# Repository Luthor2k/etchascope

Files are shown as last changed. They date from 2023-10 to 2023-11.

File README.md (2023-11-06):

# EtchaSkope
Supercon 2023 Badge Expansion
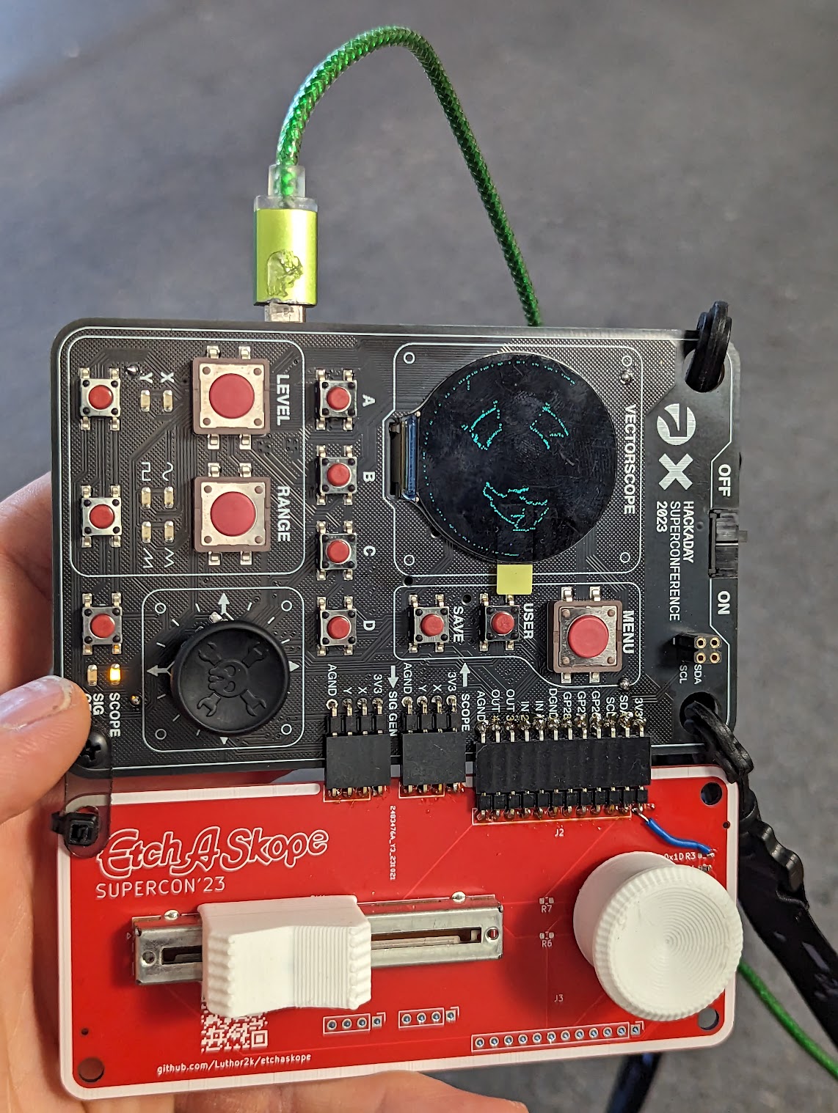
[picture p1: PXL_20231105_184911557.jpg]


## Two bodge wires needed!
The high speed DAQ on the badge was the wrong choice, reroute the linear pot to the RP2040 ADC. Also need to bring 3.3V to a pull up because of a routing mistake.
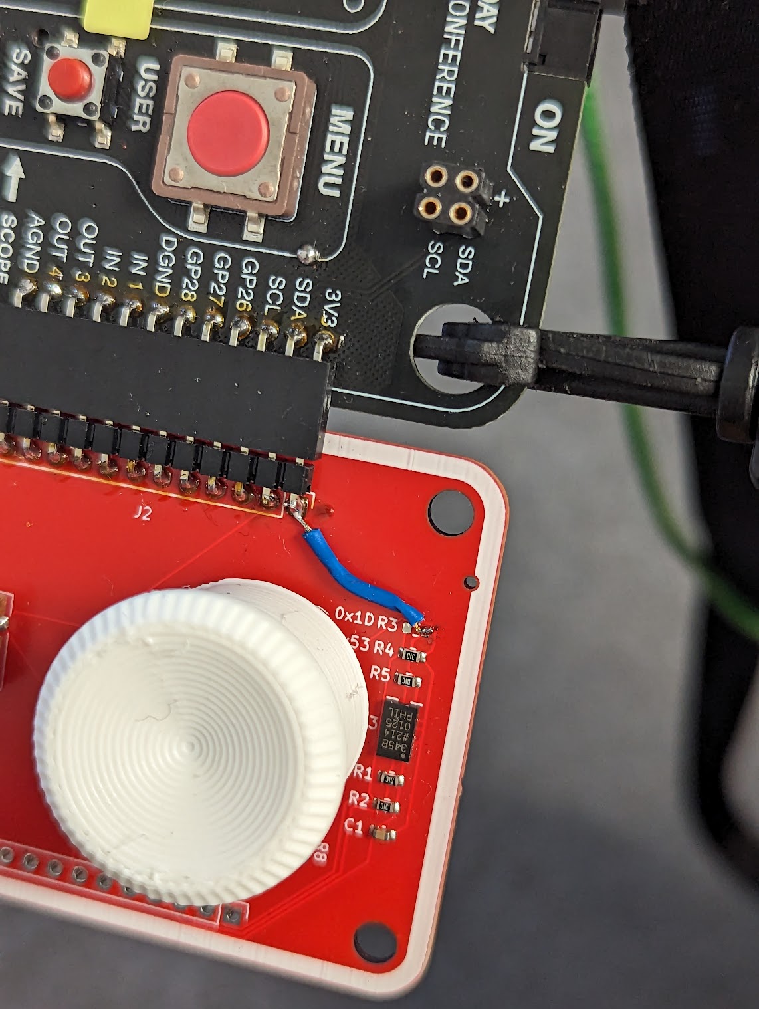
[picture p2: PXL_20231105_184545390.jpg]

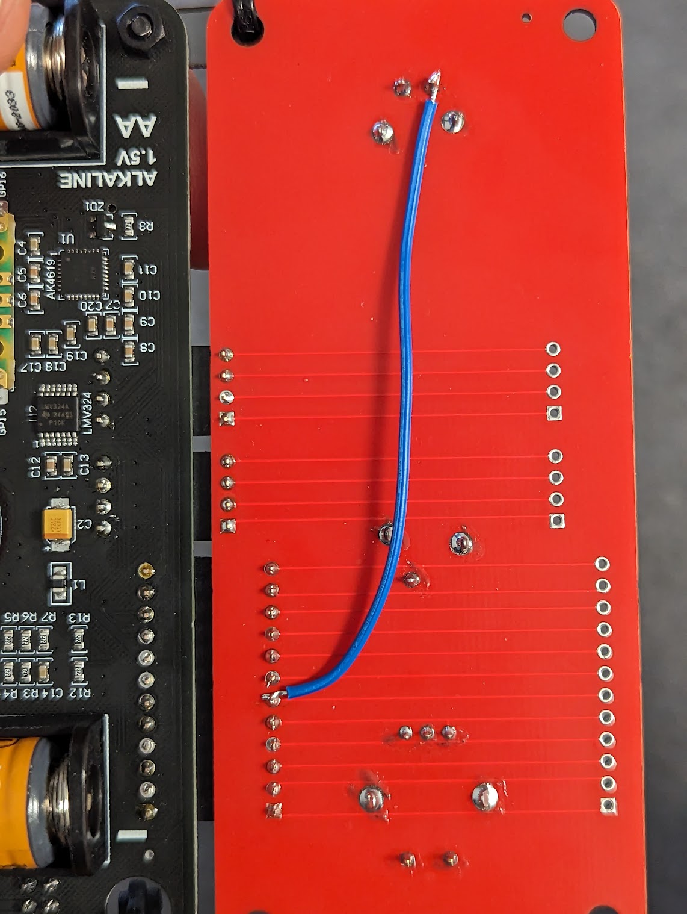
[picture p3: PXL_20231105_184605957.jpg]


### Critical Features
* badge; round LCD so polar coordinate system
  * one rotary potentiometer
  * one linear potentiometer
* mechnically attaches to supercon badge so header isn't destroyed
* red PCB incase the case doesnt print / get designed in time
* white printed/spray painted control knobs
* flip-to-erase
  * accelerometer with available micropython library
  * simple tilt switch if $$ getting $$$
* header pass through presents same mounting points / spacing for additional expansion boards

### TODO
* component selectionDONE
* pcb designDONE
* pcb submissionDONE
* enclosure designNOTHAPPENING
* print enclosures; Knobs printed last minute in white PLA by SethK, thanks Seth!
* spray knobsNOTREQ

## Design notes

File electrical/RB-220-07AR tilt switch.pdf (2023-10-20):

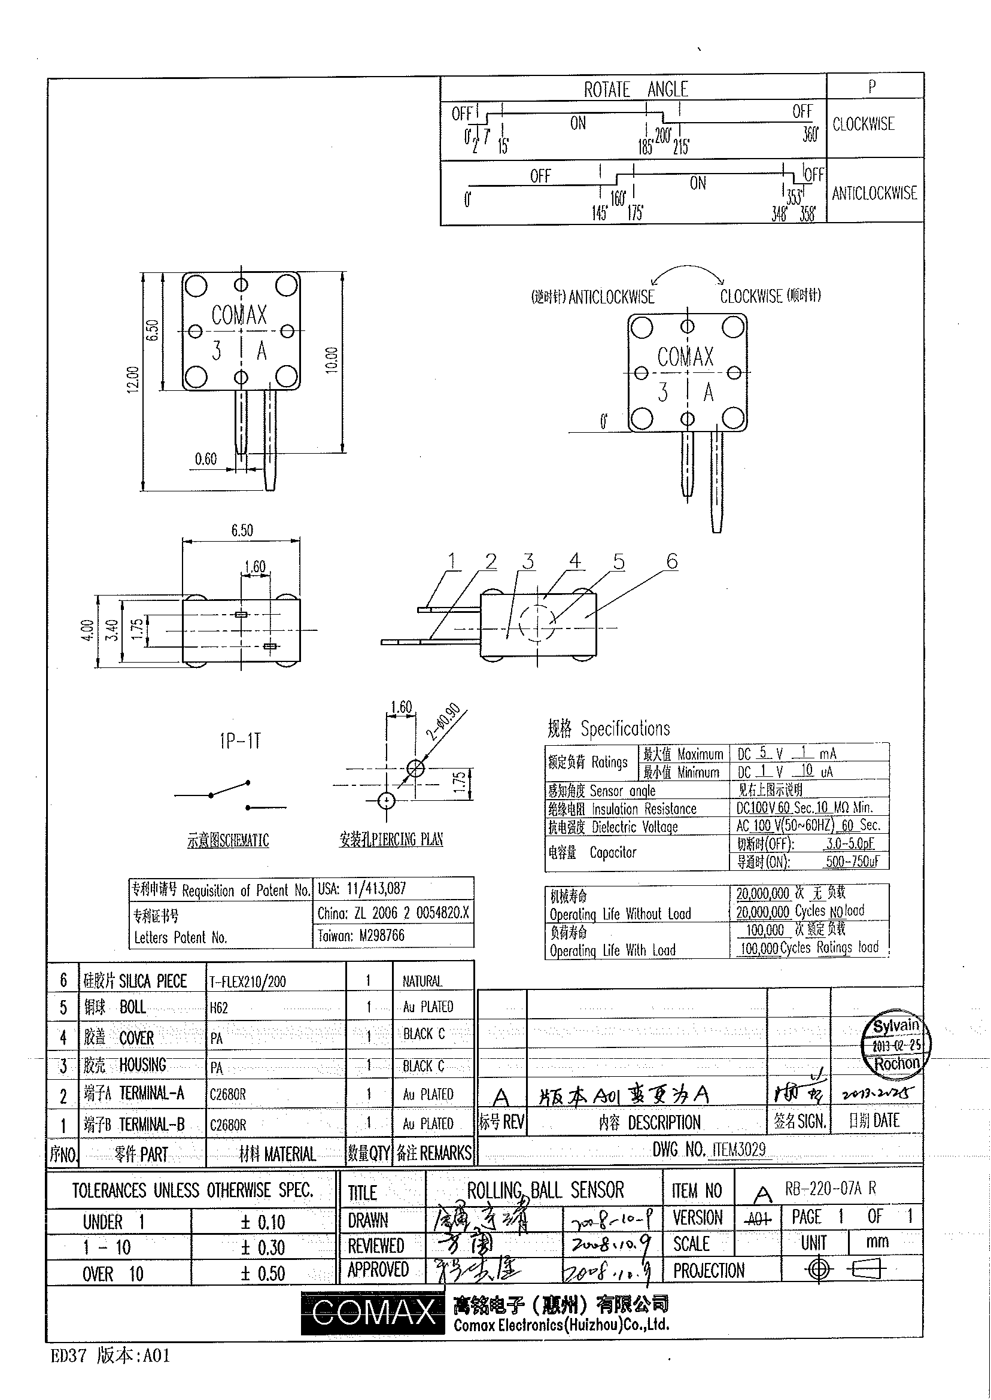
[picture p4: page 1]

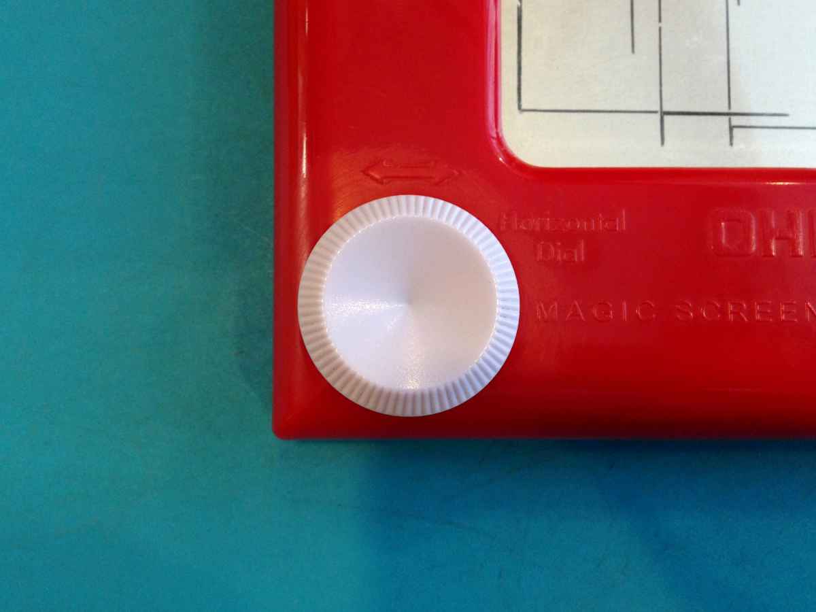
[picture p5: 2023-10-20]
mechanical/knob.jpg

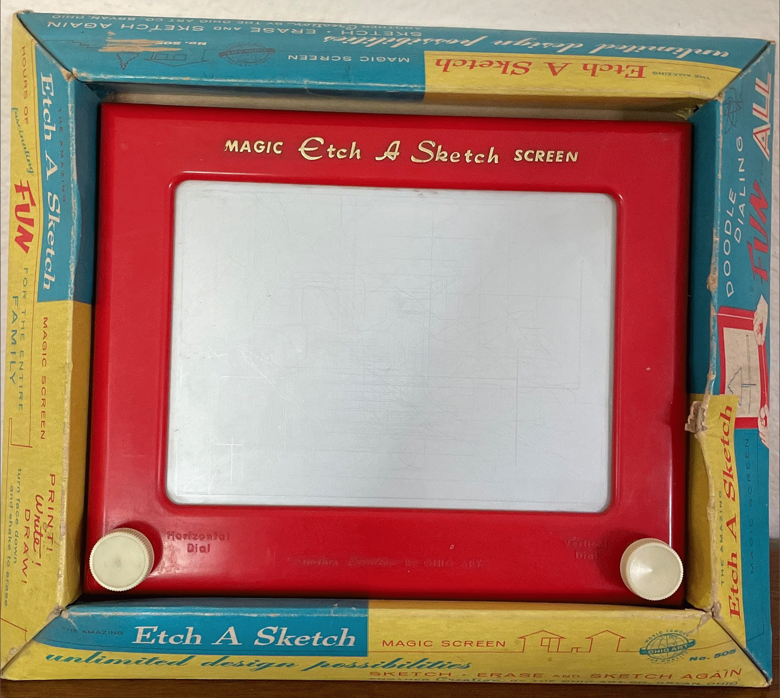
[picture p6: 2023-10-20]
mechanical/etchasketch1960.png

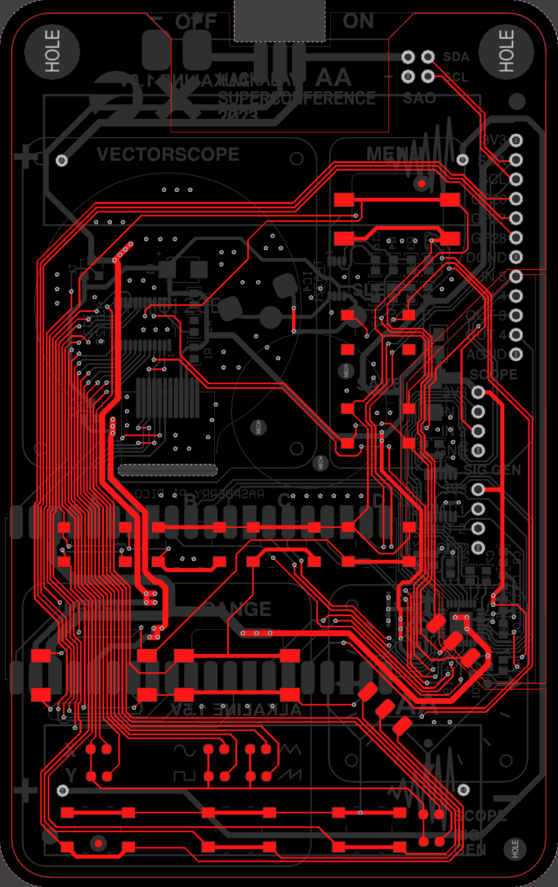
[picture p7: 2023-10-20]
mechanical/VECTOR_Top.jpg

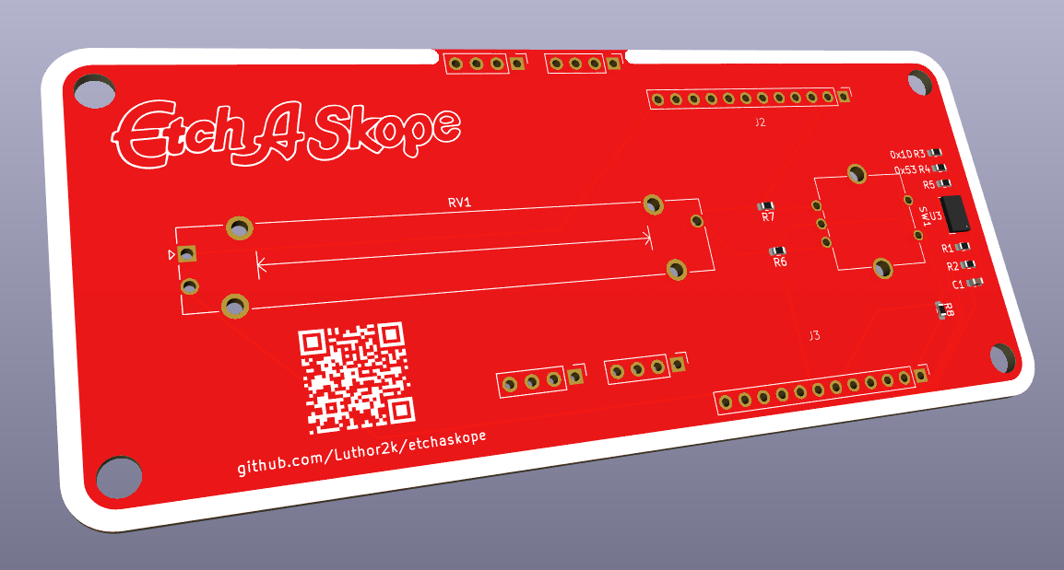
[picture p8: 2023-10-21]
render.png

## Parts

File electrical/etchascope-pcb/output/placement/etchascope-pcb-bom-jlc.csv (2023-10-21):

Designation | Designator | Footprint | JLCPCB Part #
10k | R4,R5,R2,R1 | R_0603_1608Metric | C25804
0.1uF | C1 | C_0603_1608Metric | C14663
ADXL343 | U3 | LGA-14_3x5mm_P0.8mm_LayoutBorder1x6y | C579456

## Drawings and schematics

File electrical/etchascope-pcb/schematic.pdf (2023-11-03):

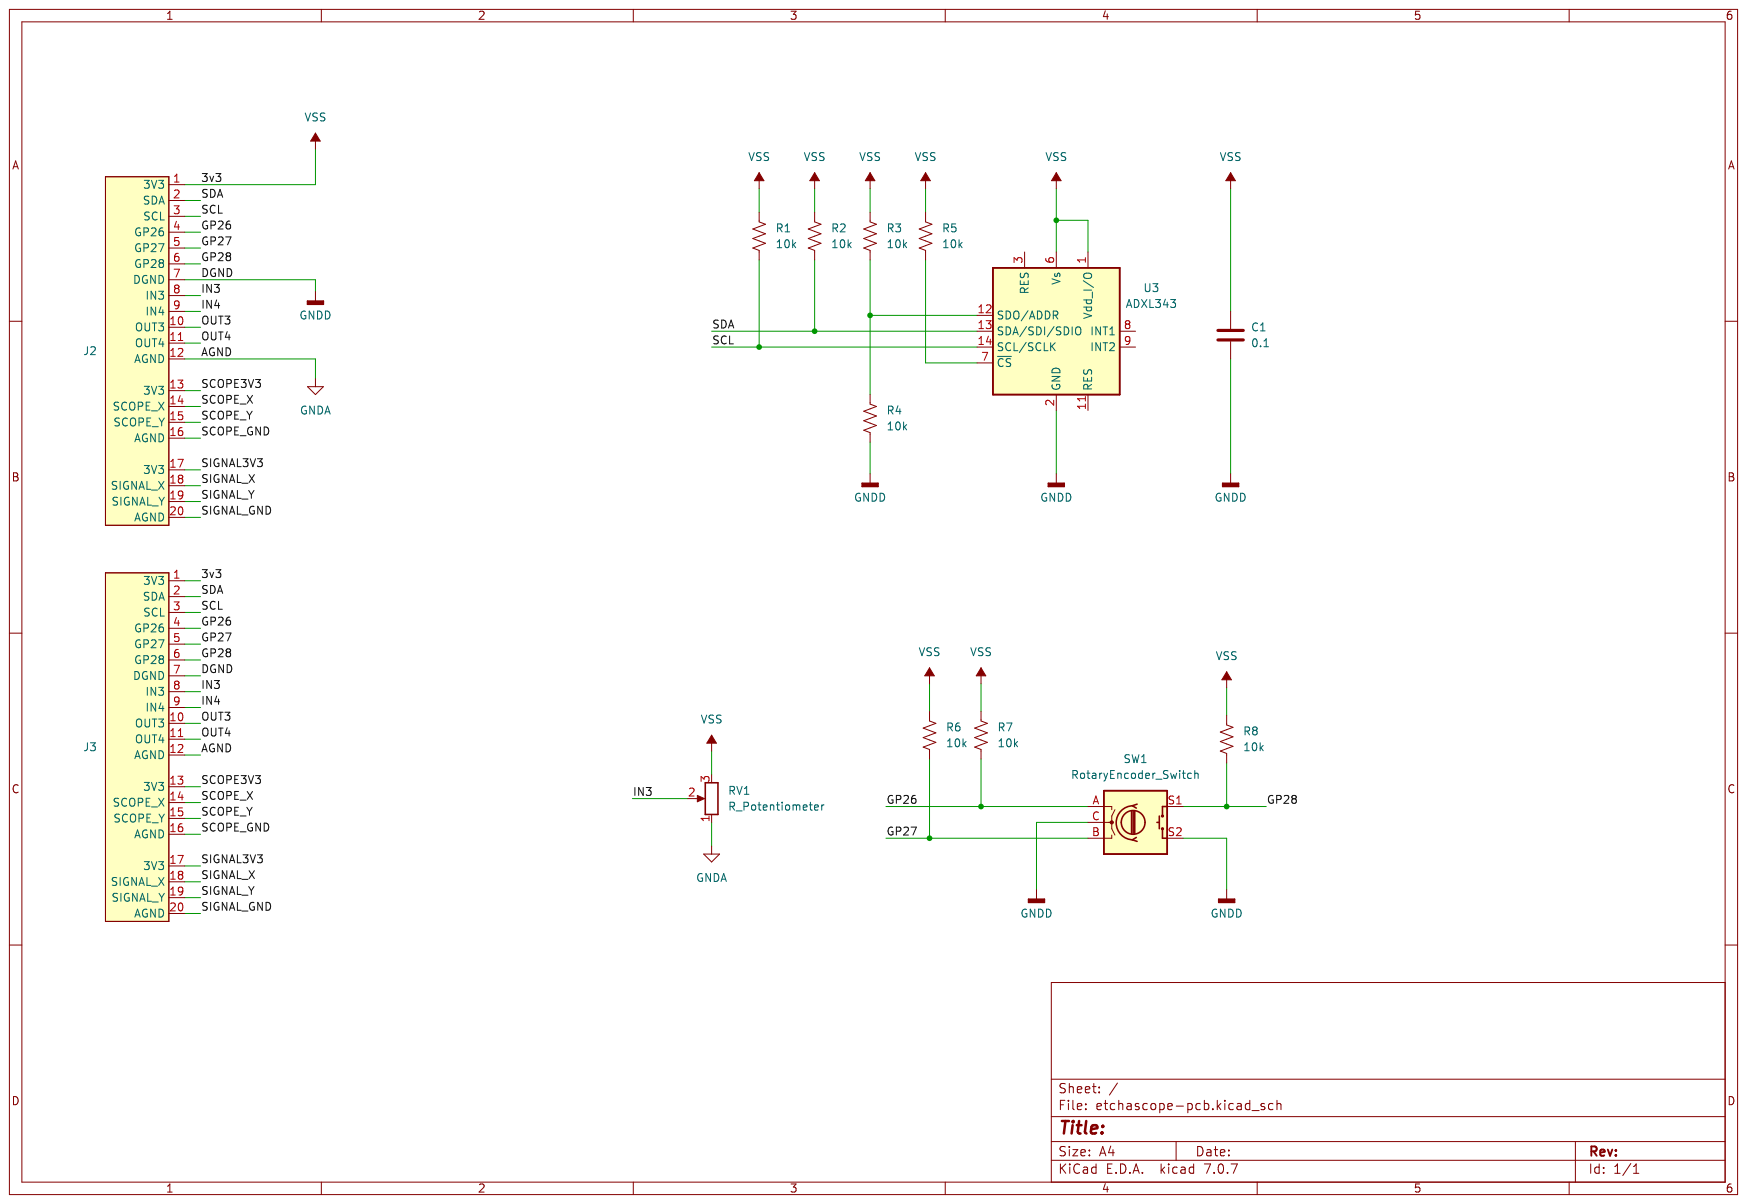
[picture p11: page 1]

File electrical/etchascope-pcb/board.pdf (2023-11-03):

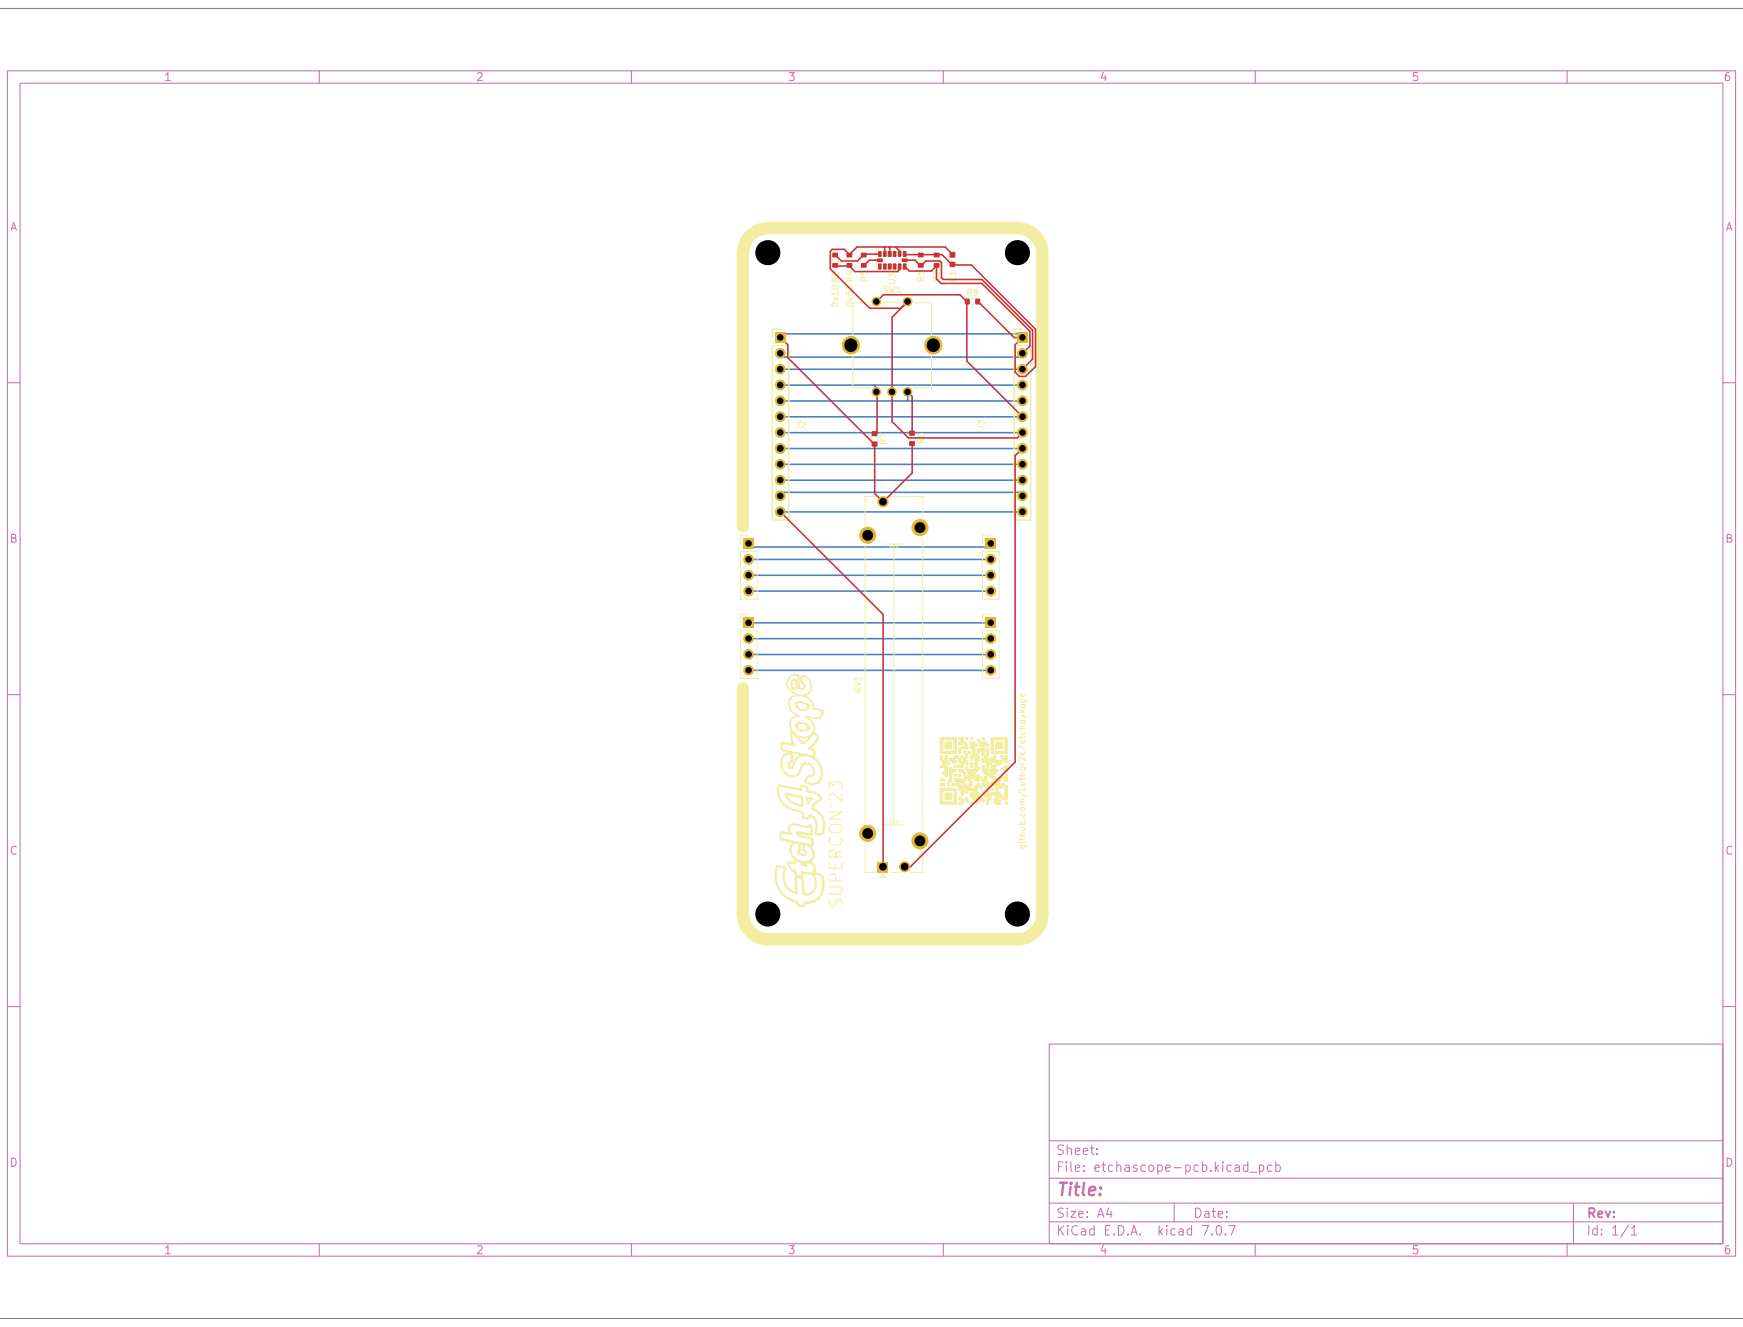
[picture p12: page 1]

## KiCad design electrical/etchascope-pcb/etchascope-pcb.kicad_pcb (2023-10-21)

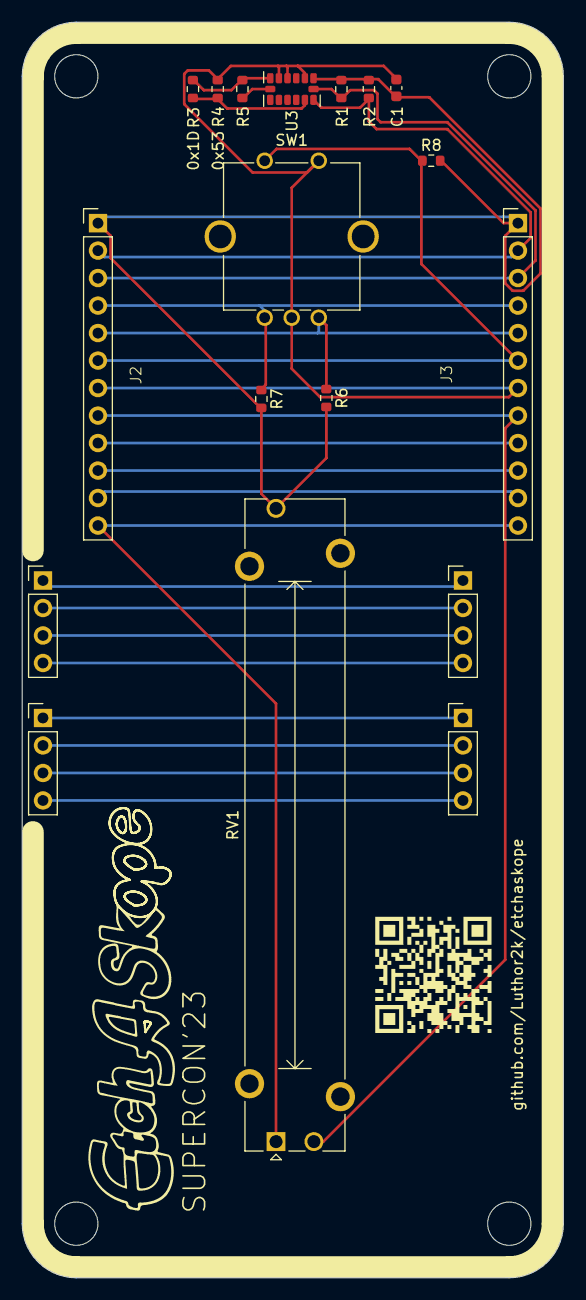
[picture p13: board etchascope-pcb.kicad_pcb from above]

Board: 2 copper layers, 50.0 x 116.0 mm, 14 parts (0 on the bottom side), 14 nets.

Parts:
C1: 0.1; C_0603_1608Metric
J2: superconBadge23-expansion-left
J3: superconBadge23-expansion-right
R1, R2, R3, R4, R5, R6, R7, R8: 10k; R_0603_1608Metric
RV1: R_Potentiometer; Potentiometer_Bourns_PTA4543_Single_Slide
SW1: RotaryEncoder_Switch; RotaryEncoder_Bourns_Vertical_PEC12R-3xxxF-Sxxxx
U3: ADXL343; LGA-14_3x5mm_P0.8mm_LayoutBorder1x6y

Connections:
/GP26: J2.4 (GP26), J3.4 (GP26), R7.1, SW1.A
/GP27: J2.5 (GP27), J3.5 (GP27), R6.1, SW1.B
/GP28: J2.6 (GP28), J3.6 (GP28), R8.1, SW1.S1
/IN3: J2.8 (IN3), J3.8 (IN3), RV1.2
/IN4: J2.9 (IN4), J3.9 (IN4)
/OUT3: J2.10 (OUT3), J3.10 (OUT3)
/OUT4: J2.11 (OUT4), J3.11 (OUT4)
/SCL: J2.3 (SCL), J3.3 (SCL), R1.1, U3.14 (SCL/SCLK)
/SDA: J2.2 (SDA), J3.2 (SDA), R2.1, U3.13 (SDA/SDI/SDIO)
GNDA: J2.12 (AGND), J3.12 (AGND), RV1.1
GNDD: C1.2, J2.7 (DGND), J3.7 (DGND), R4.1, SW1.C, SW1.S2, U3.2 (GND), U3.4 (GND), U3.5 (GND)
unnamed: R3.1, R4.2, U3.12 (SDO/ADDR)
unnamed: R5.1, U3.7 (~CS)
VSS: C1.1, J2.1 (3V3), J3.1 (3V3), R1.2, R2.2, R3.2, R5.2, R6.2, R7.2, R8.2, RV1.3, U3.1 (Vdd_I/O), U3.6 (Vs)

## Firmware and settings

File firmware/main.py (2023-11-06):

from machine import Pin, SPI, SoftSPI, I2C,ADC
import pin_defs
import gc9a01
import gc
import rp2
import sys
from rotary_irq_rp2 import RotaryIRQ
import time
import ustruct
import math

# Constants

# I2C address
ADXL343_ADDR = 0x53

# Registers
REG_DEVID = 0x00
REG_POWER_CTL = 0x2D
REG_DATAX0 = 0x32

# Other constants
DEVID = 0xE5
SENSITIVITY_2G = 1.0 / 256  # (g/LSB)
EARTH_GRAVITY = 9.80665     # Earth's gravity in [m/s^2]
 
def reg_write(i2c, addr, reg, data):
    """
    Write bytes to the specified register.
    """
    
    # Construct message
    msg = bytearray()
    msg.append(data)
    
    # Write out message to register
    i2c.writeto_mem(addr, reg, msg)
    
def reg_read(i2c, addr, reg, nbytes=1):
    """
    Read byte(s) from specified register. If nbytes > 1, read from consecutive
    registers.
    """
    
    # Check to make sure caller is asking for 1 or more bytes
    if nbytes < 1:
        return bytearray()
    
    # Request data from specified register(s) over I2C
    data = i2c.readfrom_mem(addr, reg, nbytes)
    
    return data

class Screen():
    def __init__(self, softSPI=False):
        self.softSPI = softSPI
        self.sck  = Pin(pin_defs.sck, Pin.OUT)
        self.data = Pin(pin_defs.data, Pin.OUT)
        self.dc   = Pin(pin_defs.dc, Pin.OUT)
        self.init()

    def deinit(self):
        self.spi.deinit()
        ## this does not appear to de-initialize the DMAs -- the enable bits are still set
        del(self.spi)
        del(self.tft)
        gc.collect()

    def init(self):
        if self.softSPI:
            self.spi = SoftSPI(baudrate=10_000_000, sck=self.sck, mosi=self.data, miso=Pin(pin_defs.throwaway))
        else:
            self.spi = SPI(0, baudrate=40_000_000, sck=self.sck, mosi=self.data)
        
        self.tft = gc9a01.GC9A01(self.spi, 240, 240,
                            reset     = Pin(pin_defs.reset, Pin.OUT),
                            cs        = Pin(pin_defs.throwaway, Pin.OUT), ## not used, grounded on board
                            dc        = self.dc,
                            backlight = Pin(pin_defs.throwaway, Pin.OUT), ## not used, always on
                            rotation  = 0)
        self.tft.init()   
        self.tft.fill(gc9a01.color565(10,15,10))


if __name__ == "__main__":

    import time
    import random

    ## instantiate and init
    s = Screen()

    ## For everything you can do with the GC9A01 library:
    ## https://github.com/russhughes/gc9a01_mpy

    s.tft.fill(gc9a01.BLACK)

    phosphor_bright = gc9a01.color565(120, 247, 180)
    phosphor_dark   = gc9a01.color565(45, 217, 80)

    # Initialize I2C
    i2c = I2C(1, sda=Pin(14), scl=Pin(15), freq=100000)   

    # Print out any addresses found
    devices = i2c.scan()

    if devices:
        for d in devices:
            print(hex(d))

    #initialize the ADXL345
    # Read device ID to make sure that we can communicate with the ADXL343
    data = reg_read(i2c, ADXL343_ADDR, REG_DEVID)
    if (data != bytearray((DEVID,))):
        print("ERROR: Could not communicate with ADXL343")
        sys.exit()
        
    # Read Power Control register
    data = reg_read(i2c, ADXL343_ADDR, REG_POWER_CTL)
    print(data)

    # Tell ADXL343 to start taking measurements by setting Measure bit to high
    data = int.from_bytes(data, "big") | (1 << 3)
    reg_write(i2c, ADXL343_ADDR, REG_POWER_CTL, data)

    # Test: read Power Control register back to make sure Measure bit was set
    data = reg_read(i2c, ADXL343_ADDR, REG_POWER_CTL)
    print(data)

    #attach rotary interrupt
    r = RotaryIRQ(pin_num_clk=26,
              pin_num_dt=27,
              pull_up=True,
              min_val=0,
              max_val=360,
              incr=2,
              reverse=False,
              range_mode=RotaryIRQ.RANGE_WRAP)

    val_old = r.value()
    
    adc = ADC(Pin(28))     # create ADC object on linear pot pin

    while True:
        val_new = r.value()
        slider_adc_value = 65536 - adc.read_u16()  #invert so the linear pot is 'distance from center'

        # Read X, Y, and Z values from registers (16 bits each)
        data = reg_read(i2c, ADXL343_ADDR, REG_DATAX0, 6)

        # Convert 2 bytes (little-endian) into 16-bit integer (signed)
        acc_x = ustruct.unpack_from("<h", data, 0)[0]
        acc_y = ustruct.unpack_from("<h", data, 2)[0]
        acc_z = ustruct.unpack_from("<h", data, 4)[0]

        # Convert measurements to [m/s^2]
        acc_x = acc_x * SENSITIVITY_2G * EARTH_GRAVITY
        acc_y = acc_y * SENSITIVITY_2G * EARTH_GRAVITY
        acc_z = acc_z * SENSITIVITY_2G * EARTH_GRAVITY

        if val_old != val_new:
            val_old = val_new

            rads = 2*math.pi*(float(val_new/360))
            print("rads: ", rads)

            print("slider_adc_value = ", slider_adc_value)
            slider_factor = 120 * slider_adc_value / 65536
            print("slider_factor = ", slider_factor)

            #draw a pixel slider_factor between the center and the edge
            etch_x = int(math.cos(rads) * slider_factor) + 120
            etch_y = int(math.sin(rads) * -1 * slider_factor) + 120
            print("etch_x = ", etch_x, "etch_y = ", etch_y)
            #s.tft.pixel(etch_x, etch_y, phosphor_bright)
            s.tft.fill_rect(etch_x - 1, etch_y - 1, 3, 3, phosphor_bright)

        if acc_z < -5:
            s.tft.fill(gc9a01.BLACK)
            print("flipped!")

        time.sleep_ms(50)

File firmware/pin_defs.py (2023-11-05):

## Hardware GPIO # pin defines

## Screen pins
sck   = const(2)
data  = const(3)
reset = const(4)
dc    = const(5)

## there are a number of libs that require pins that we don't provide
## pass them the on-board LED.  It's unlikely to hurt.
throwaway = const(25)
debug     = const(27)

user_button    = const(19)
audio_shutdown = const(22)

## Codec pins
## clocks
mclk      = const(7)
bit_clock = const(8)
lr_clock  = const(9)
## data
sd_in     = const(13) ## In 3/4 (Y=L, X=R)
sd_out    = const(10) ## Out 1/2 (Y=L, X=R)
## config
pdn       = const(6)
i2c_scl   = const(21)
i2c_sda   = const(20)


#Exp pins
i2c_exp_scl = const(15)
i2c_exp_sda = const(14)

## some globally useful pin inits
# debug_pin          = machine.Pin(debug, machine.Pin.OUT, value=0)
# audio_shutdown_pin = machine.Pin(audio_shutdown, machine.Pin.OUT, value=1)
# user_button        = machine.Pin(user_button, machine.Pin.IN)


#sd_in=Pin(13, Pin.IN) ## In 3/4 (Y=L, X=R)
#sd_out=Pin(10, Pin.OUT, value=0) ## Out 1/2 (Y=L, X=R)

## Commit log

2023-10-20 schematic underway
    [etchascope-pcb.kicad_pcb, etchascope-pcb.kicad_sch]
2023-10-20 pcb possibly complete
    [etchascope-pcb.kicad_pcb, etchascope-pcb.kicad_sch]
2023-10-20 logo added
    [etchascope-pcb.kicad_pcb]
2023-10-21 tidied up connectors and logo
    [etchascope-pcb-B_Cu.gbr, etchascope-pcb-B_Mask.gbr, etchascope-pcb-B_Paste.gbr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]
2023-10-21 tweaking logo
    [etchascope-pcb-B_Cu.gbr, etchascope-pcb-B_Mask.gbr, etchascope-pcb-B_Paste.gbr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]
2023-10-21 PCBWAY submission
    [etchascope-pcb-bottom-pos.csv, etchascope-pcb-top-pos-components-offset-left.csv, etchascope-pcb-top-pos.xls]
2023-11-03 schematic pdfs
2023-11-05 accelerometer working after jumping pin6 Vs to 3v3, woops!
2023-11-06 pixel size increased to 3x3, encoder speed increased 2x
